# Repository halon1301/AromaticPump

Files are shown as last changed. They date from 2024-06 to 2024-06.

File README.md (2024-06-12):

# M5 Blowover Pump

## This device may be used in ways which can be unsafe.  I take no responsibility for unsafe usage, be smart and think with the head on your shoulders, not between your legs.
## DO NOT USE THIS DEVICE ALONE
## DO NOT USE WITH VOLATILE COMPOUNDS
## DO NOT USE WHILE INTOXICATED

Now that I've got the safety stuff done, let's get on to the fun stuff.

### Full BOM

This BOM assumes you're using the provided circuit board designs, if you're going to use strip/protoboard to build this, 
you'll need to account for the differences

| Count | Part | Supplier | Link |
|---|---|---|---|
| 1 | Main Circuit Board | PCBWay | n/a |
| 1 | M5Stack Core 2 | 	DigiKey | https://www.digikey.ca/en/products/detail/m5stack-technology-co-ltd/K010/13151126 |
| 1 | Simple RF M4 315Mhz Momentary	 | Adafruit | https://www.adafruit.com/product/1096 |
| 1 | 2 Button Key Fob	 | Adafruit	 | https://www.adafruit.com/product/1391 |
| 1 | 4 Button Key Fob | 	Adafruit	 | https://www.adafruit.com/product/1095 |
| 1 | 12V Pump	 | Amazon	 | https://a.co/d/cortGed |
| 1 | 12V 2A Power Adapter	 | Amazon	 | https://a.co/d/3SDBTkm |
| 1 | DRV8871 DC Motor Driver(Adafruit Brand)	 | Amazon or Adafruit	 | https://www.adafruit.com/product/3190 |
| 1 | 7-24V to 5V Buck Converter ( RB-Dfr-956) | RobotShop	 | https://www.robotshop.com/products/dfrobot-dc-dc-buck-converter-7-24v-to-5v-4a |
| 1 | Barrel Plug Adapter 5.5mm | Amazon | https://a.co/d/0rlC4Ci |
| 3 | 10kOhm Resistors | Digikey | https://www.digikey.ca/en/products/detail/yageo/CFR-25JB-52-10K/338 |
| 3 | 22kOhm Resistors | DigiKey | https://www.digikey.ca/en/products/detail/yageo/CFR-25JB-52-22K/1306 |
| 1 | Some kind of physical latching on/off switch | Amazon | https://a.co/d/hDef00k |
| 1 | Silicone Tubing | Amazon | https://a.co/d/bUvRTfo | |
| 2 | Barb Through fitting | Amazon | https://a.co/d/0NNg51N |
| 2 | FPC 30 Pin boards | Amazon | https://a.co/d/jerJJ3a |
| 1| 30 Pin ribbon cable | Amazon | https://a.co/d/dCT5ZlU |

The 4 button fob is entirely optional, as it does the same things the touchscreen on the m5stack already does.  The 2 
button remote is for a sub to use, if you don't want this, consider it optional. Only button 2 is used on the 2 button 
remote (I use button 1 for a lube pump, so it's not wired up).

There are included PCB diagrams made in KiCAD, you can get them printed with PCBWay, but this whole project could easily
be made using proto/strip board and wires.

STLs for a case are also included, these however assume you are using the PCB included with the project, please remix 
and create your own for your use case!

### Assembly
All components are through hole, this is to keep it easy for people to make on their own with basic soldering skills, 
and without requiring special PCBs or other things that may be slightly more esoteric.

The designed PCB uses standard expansion pins for most things, the connectors for the switch and the 12v to the motor 
driver are designed to use a screw block, but you really could just solder wires into the hole and call it done.  Mounting 
points on the board are designed to use M3 screws, I'd recommend a nylon washer between the screw and the board, if you 
use inserts in your case, you should probably put something on the other side, but it's mostly because I'm paranoid 
about shorts.  In my design I use a pair of breakout boards and a 30p ribbon cable to lift the M5 stack off the board 
and give me nice clearance, once again, these are optional, you could do this however you want.

If your using the provided PCB design, you'll want to use some rosin flux, it'll make your life easier.  Solder 
everything to the board where labeled.

Don't connect your M5Stack to the board when you flash it, the USB 5v is not isolated from the 5v bus, and you'll get 
weird results, or fuck your computer up.

Bring up platformIO in your IDE of choice, and run the build, then upload to your board and you are good to plug it in. 
Power up the pump, and you're ready to go.

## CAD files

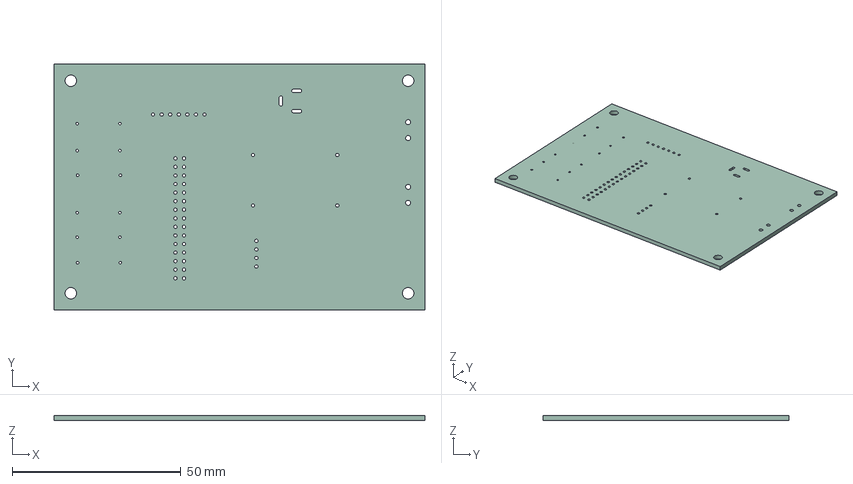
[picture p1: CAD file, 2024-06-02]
PCBLayout/popperpump/popperPump/popperPump.step
110.0 x 73.0 x 1.60 mm

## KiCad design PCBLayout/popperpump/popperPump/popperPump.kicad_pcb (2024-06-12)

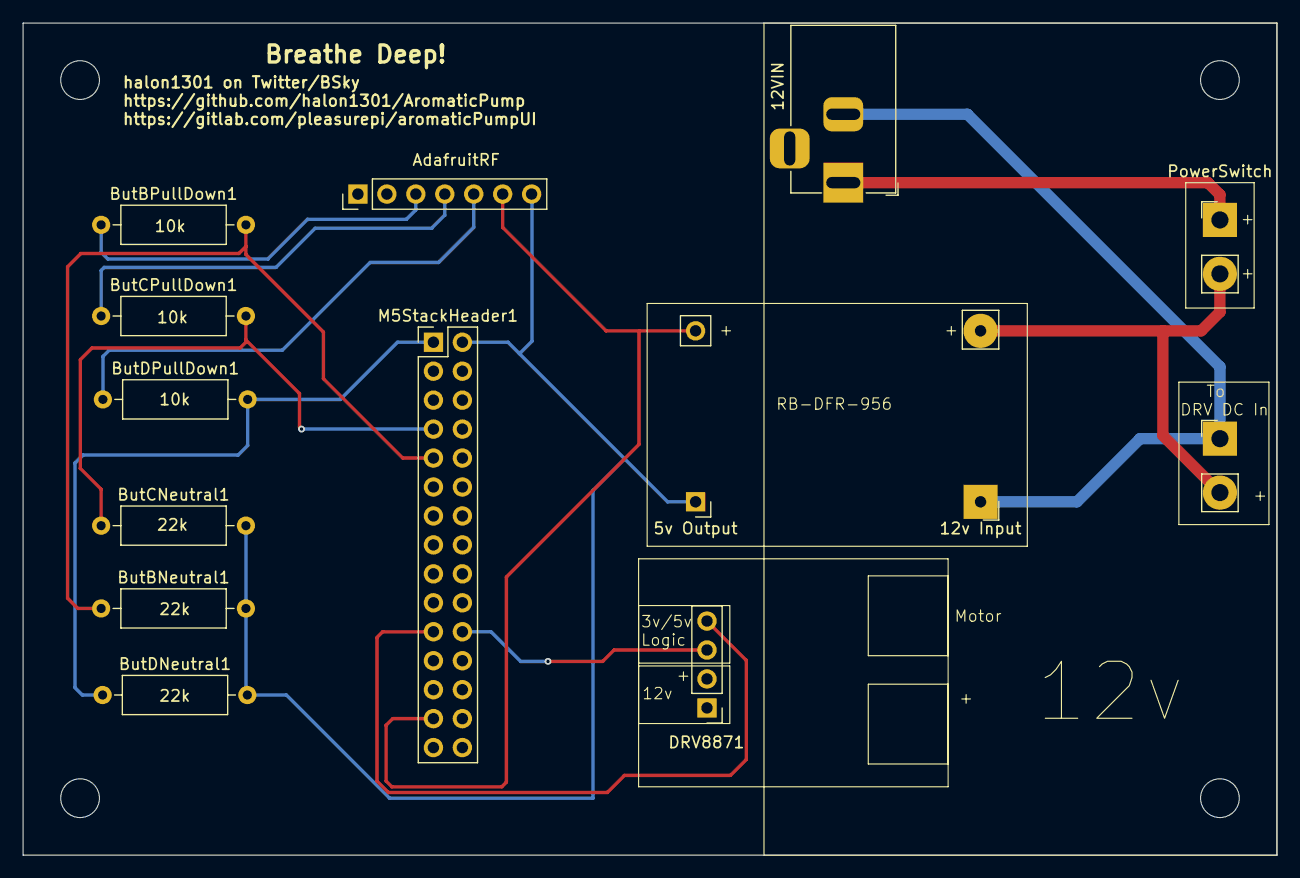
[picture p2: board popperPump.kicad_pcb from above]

Board: 2 copper layers, 110.0 x 73.0 mm, 14 parts (0 on the bottom side), 10 nets.

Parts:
5v Output: RB-Dfr-956-5vout; PinHeader_1x02_P2.54mm_Vertical-BuckConverter-DFR-956
12VIN: Barrel_Jack; BarrelJack_Horizontal
12v Input: RB-Dfr-956-12vin; PinHeader_1x02_P2.54mm_Vertical-BuckConverter-DFR-956
AdafruitRF: Adafruit-1096; PinHeader_1x07_P2.54mm_Vertical
ButBNeutral1: 22k; R_Axial_DIN0309_L9.0mm_D3.2mm_P12.70mm_Horizontal
ButBPullDown1: 10k; R_Axial_DIN0309_L9.0mm_D3.2mm_P12.70mm_Horizontal
ButCNeutral1: 22k; R_Axial_DIN0309_L9.0mm_D3.2mm_P12.70mm_Horizontal
ButCPullDown1: 10k; R_Axial_DIN0309_L9.0mm_D3.2mm_P12.70mm_Horizontal
ButDNeutral1: 22k; R_Axial_DIN0309_L9.0mm_D3.2mm_P12.70mm_Horizontal
ButDPullDown1: 10k; R_Axial_DIN0309_L9.0mm_D3.2mm_P12.70mm_Horizontal
DRV1: DRV8871-VIN-12v; PinHeader_1x02_ForScrewBlock-1.5mmHole
DRV8871: DRV8871; PinHeader_1x04_P2.54mm_Vertical
M5StackHeader1: M5StackGPIO; PinHeader_2x15_P2.54mm_Vertical
PowerSwitch: SW_SPDT; PinHeader_1x02_ForScrewBlock-1.5mmHole

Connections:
GND: 5v Output.1, 12VIN.2, 12v Input.1, AdafruitRF.7, ButBNeutral1.2, ButCNeutral1.2, ButDNeutral1.2, DRV1.1, M5StackHeader1.2
unnamed: AdafruitRF.3, ButBPullDown1.1
unnamed: AdafruitRF.4, ButCPullDown1.1
unnamed: AdafruitRF.5, ButDPullDown1.1
unnamed: DRV8871.3, M5StackHeader1.22
unnamed: DRV8871.4, M5StackHeader1.21
unnamed: ButDNeutral1.1, ButDPullDown1.2, M5StackHeader1.1
unnamed: ButCNeutral1.1, ButCPullDown1.2, M5StackHeader1.7
unnamed: ButBNeutral1.1, ButBPullDown1.2, M5StackHeader1.9
VCC: 5v Output.2, 12VIN.1, 12v Input.2, AdafruitRF.6, M5StackHeader1.27, PowerSwitch.1 (A), PowerSwitch.2 (B)

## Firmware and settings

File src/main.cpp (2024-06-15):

#include <M5Unified.h>
#include <Arduino.h>
#include <lvgl.h>
#include "ui/ui.h"
#include "main.h"
#include "lib/pumpAction.h"
#include "lib/remote.h"
#include <esp_timer.h>
#include "lib/flow.h"

const int displayHorizonal = 320;
const int displayVertical = 240;

const int remoteUserPin = 26; // Button B
const int flowUpPin = 35; // Button C
const int flowDownPin = 25; // Button D
int remoteUserStatus = 0;
int flowUpStatus = 0;
int flowDownStatus = 0;

// The percentage of flow rate.  This is directly related to the PWM value passed on PIN2 of the motor driver, it starts and 75% and goes up or down from there
// 0 is 0%, 255 is 100%
unsigned int flowRate = 75; // 0.75 * 255 = 192
unsigned int flowRateAdj = 5; // The percentage the flow rate will change by


// Safety Timing
unsigned long runTimer = 300; // The period of time passed when the runLimit gets reset
unsigned long runMaxTime = 240; // The maximum amount of time in runTimer the pump can run, after this, it locks out until runTimer passes
unsigned long runTotalTime; // Total run time counter

unsigned int countdownTimer = 30;
bool runAllowed = true;
bool runstate = false;
bool boot = true; // If the m5stack has just booted, this is to capture the disclaimer timeout

unsigned long bootTime = 0;
unsigned long initialStartTime = 0;
unsigned long startTime;
unsigned long lastTime = 0;
unsigned long sleepStartTime = 0;
unsigned long currentTime;
unsigned long runElapsedTime = 0;

lv_display_t *display;
lv_indev_t *indev;
static lv_draw_buf_t *draw_buf1;

// Display flushing
void my_disp_flush(lv_display_t *disp, const lv_area_t *area, uint8_t *px_map) {
    uint32_t w = (area->x2 - area->x1 + 1);
    uint32_t h = (area->y2 - area->y1 + 1);

    lv_draw_sw_rgb565_swap(px_map, w*h);
    M5.Display.pushImageDMA<uint16_t>(area->x1, area->y1, w, h, (uint16_t *)px_map);
    lv_disp_flush_ready(disp);
}

uint32_t my_tick_function() {
    return(esp_timer_get_time() / 1000LL);
}

void my_touchpad_read(lv_indev_t * drv, lv_indev_data_t * data) {
   M5.update();
   auto count = M5.Touch.getCount();
   if (count == 0) {
       data->state = LV_INDEV_STATE_RELEASED;
   } else {
       auto touch = M5.Touch.getDetail(0);
       data->state = LV_INDEV_STATE_PRESSED;
       data->point.x = touch.x;
       data->point.y = touch.y;
   }
}

static void event_cb(lv_event_t *e)
{
    lv_event_code_t code = lv_event_get_code(e);
    lv_obj_t *label = reinterpret_cast<lv_obj_t *>(lv_event_get_user_data(e));

    switch (code)
    {
        case LV_EVENT_PRESSED:
            lv_label_set_text(label, "The last button event:\nLV_EVENT_PRESSED");
            break;
        case LV_EVENT_CLICKED:
            lv_label_set_text(label, "The last button event:\nLV_EVENT_CLICKED");
            break;
        case LV_EVENT_LONG_PRESSED:
            lv_label_set_text(label, "The last button event:\nLV_EVENT_LONG_PRESSED");
            break;
        case LV_EVENT_LONG_PRESSED_REPEAT:
            lv_label_set_text(label, "The last button event:\nLV_EVENT_LONG_PRESSED_REPEAT");
            break;
        default:
            break;
    }
}

void setup() {
    auto cfg = M5.config();
    M5.begin(cfg);
    pinMode(remoteUserPin, INPUT);
    pinMode(flowUpPin, INPUT);
    pinMode(flowDownPin, INPUT);
    pinMode(motorPin1, OUTPUT);
    pinMode(motorPin2, OUTPUT);
    M5.Display.setEpdMode(epd_mode_t::epd_fast);
    if (M5.Display.width() < M5.Display.height()) {
        M5.Display.setRotation(M5.Display.getRotation() ^ 1);
    }
    lv_init();
    lv_tick_set_cb(my_tick_function);
    display = lv_display_create(displayHorizonal, displayVertical);
    lv_display_set_flush_cb(display, my_disp_flush);
    static lv_color_t buf1[displayHorizonal * 15];
    lv_display_set_buffers(display, buf1, nullptr, sizeof(buf1), LV_DISPLAY_RENDER_MODE_PARTIAL);

    indev = lv_indev_create();
    lv_indev_set_type(indev, LV_INDEV_TYPE_POINTER);
    lv_indev_set_read_cb(indev, my_touchpad_read);
    ui_init();
    Serial.println("Initialization complete");
    bootTime = millis();

}

void loop() {
    M5.update();
    lv_task_handler();
    currentTime = millis();
    if (boot) {
      if (currentTime - bootTime >= 1000) {
          if (countdownTimer != 0) {
              countdownTimer--;
              lv_label_set_text_fmt(objects.lbl_accept_btn, "%d", countdownTimer);
              bootTime = currentTime;
          } else {
               // Timer has runout
               boot = false;
               lv_label_set_text(objects.lbl_accept_btn, "I Will Be Smart");
          }
      }
    } else {
        remoteUserStatus = digitalRead(remoteUserPin);
        flowUpStatus = digitalRead(flowUpPin);
        flowDownStatus = digitalRead(flowDownPin);



        /*
         * if pump has run for runMaxTime in the runTimer, then it needs to shut off and be locked out until the runTimer elapses
         */

        if (runstate) {
            if (runAllowed) {
                if (remoteUserStatus == 1) {
                    sleepStartTime = stopPump();
                    delay(500);
                }
                if (flowUpStatus == 1) {
                    Serial.println("FlowUpRemote");
                    flowUpdateUp();
                    delay(500);
                }
                if (flowDownStatus == 1) {
                    Serial.println("FlowDownRemote");
                    flowUpdateDown();
                    delay(500);
                }
                if (currentTime - startTimeCounter >= 1000) { // 1 sec has passed
                    if (countdownTimer != 0) {
                        countdownTimer--;
                        lv_label_set_text_fmt(objects.lbl_time_cnt, "%d", countdownTimer);
                        startTimeCounter = currentTime;
                    } else {
                        sleepStartTime = stopPump();
                        lv_label_set_text(objects.lbl_state_txt, "Off");
                        lv_label_set_text(objects.lbl_btn_on_off, "On");
                        startTimeCounter = 0;
                    }
                }
            }
        } else {
            if (remoteUserStatus == 1) {
                startTime = runPump(1);
                delay(500);
            } else {
                countdownTimer = 30;
                startTimeCounter = 0;
                lv_label_set_text_fmt(objects.lbl_time_cnt, "%d", countdownTimer);
            }
        }
    }
    delay(5);

}

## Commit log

2024-05-02 Working +10s button
    NO SAFETY INTERLOCK
2024-05-05 Update Libraries
    Update lvgl to 9.0.0 and M5Unified
    Update of BOM
2024-05-08 Broken Commit
    This current update will not work.
    But, I'm changing my approach with the +10s idea, I think using buttons c/d on the remote and building a flow rate up/down feature is more useful than adding time.
    There's still going to be a 200s in 300s limit, or something like that, but on/off can take care of that.
    [main.cpp]
2024-06-02 Big Update
    This covers all the pending changes, and pretty much solidifies v1.0 of the project.
    It is still missing all of the safety bits to take care of max run time, and x in x.
    [popperPump.kicad_pcb, popperPump.kicad_sch, popperPump.step]
2024-06-11 2 Fixes
    - Fix the PCB layout, one of the pins was placed wrong :facepalm:
    - Remove the timing limits (coming later)
    - Update GPIO pin layout for buttons, because I'm dumb
    [popperPump-B_Cu.gbr, popperPump-B_Mask.gbr, popperPump-B_Paste.gbr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]
2024-06-12 Add in a disclaimer screen
    Create an un-skippable safety disclaimer.
    [main.cpp]
2024-06-15 Remove the i2c library
    I don't know how this got in here, I'm not using i2c on this project...
